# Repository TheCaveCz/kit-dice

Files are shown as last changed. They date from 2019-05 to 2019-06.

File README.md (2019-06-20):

# Throwing Dice / Hrací Kostka

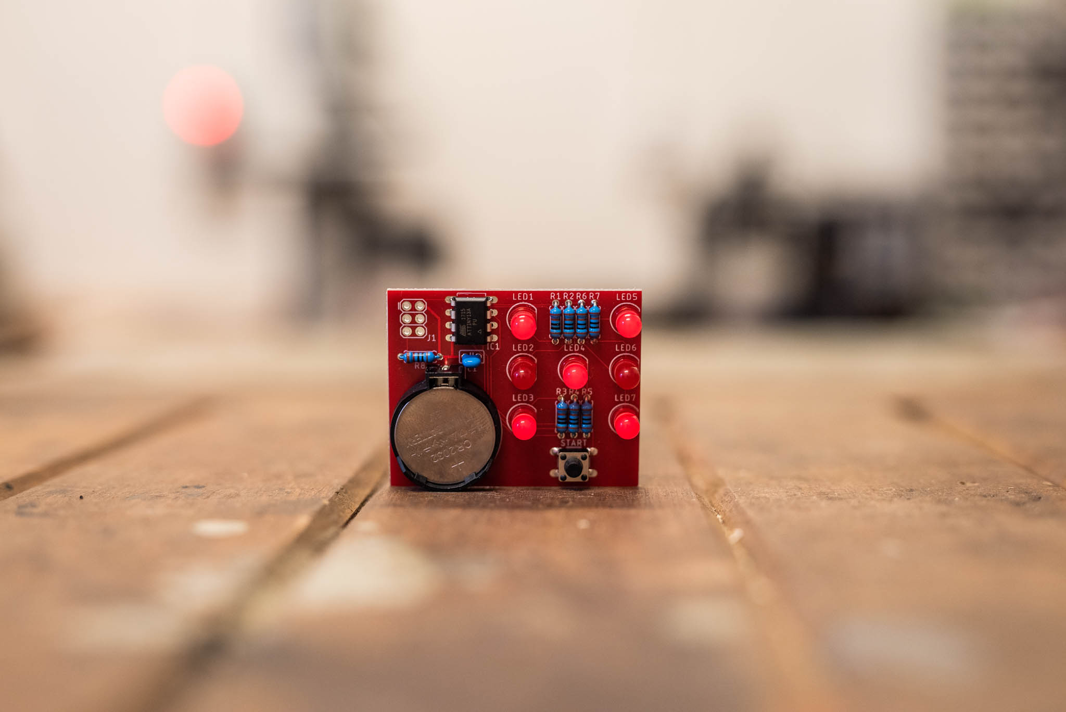
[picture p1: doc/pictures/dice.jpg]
Dice


## Česky

Stavebnice elektronické hrací kostky. Zmáčkni tlačítko start a nech pracovat náhodu.

* [Návod na stavbu](doc/manual-cz.md) ([PDF](doc/manual-cz.pdf))
* [Nahrání nového firmware](doc/firmware-cz.md)

## English

Coming coon...

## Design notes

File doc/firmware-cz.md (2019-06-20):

# Nahrání firmware

Procesory ve stavebnicích už mají program nahraný.

Kód je určený pro Arduino IDE. Pro nahrání do procesoru je nejprve potřeba nainstalovat MicroCore jádro pro ATtiny13 ([https://github.com/MCUdude/MicroCore](https://github.com/MCUdude/MicroCore) ). Žádné další knihovny nejsou potřeba.

Po nainstalování vyber v menu Tools (Nástroje) následující možnosti:

| Možnost | Hodnota |
| --- | --- |
| Board | ATTiny13 |
| BOD | 1.8V |
| LTO | Enabled |
| Clock | 1.2MHz internal OSC |

Procesor ATtiny13 nemá bootloader, takže je potřeba použít programátor (např. AVRisp nebo USBasp). Po připojení programátoru k ISP konektoru J1 v Arduino IDE zvolte možnost "Tools / Burn bootloader" a poté "Sketch / Upload"

---

Příkazová řádka pro avrdude a programátor USBasp:

```
avrdude -pattiny13 -cusbasp -B10 -Pusb -e -Ulock:w:0x3f:m -Uhfuse:w:0xfd:m -Ulfuse:w:0x2A:m -Uflash:w:dice.ino_attiny13a_1200000L.hex:i -Ueeprom:w:`hexdump -n 2 -e '2/1 "0x%02x,"' /dev/random`:m -Ulock:w:0x3e:m
```

bez nastavení generátoru náhodných čísel:

```
avrdude -pattiny13 -cusbasp -B10 -Pusb -e -Ulock:w:0x3f:m -Uhfuse:w:0xfd:m -Ulfuse:w:0x2A:m -Uflash:w:dice.ino_attiny13a_1200000L.hex:i -Ulock:w:0x3e:m
```

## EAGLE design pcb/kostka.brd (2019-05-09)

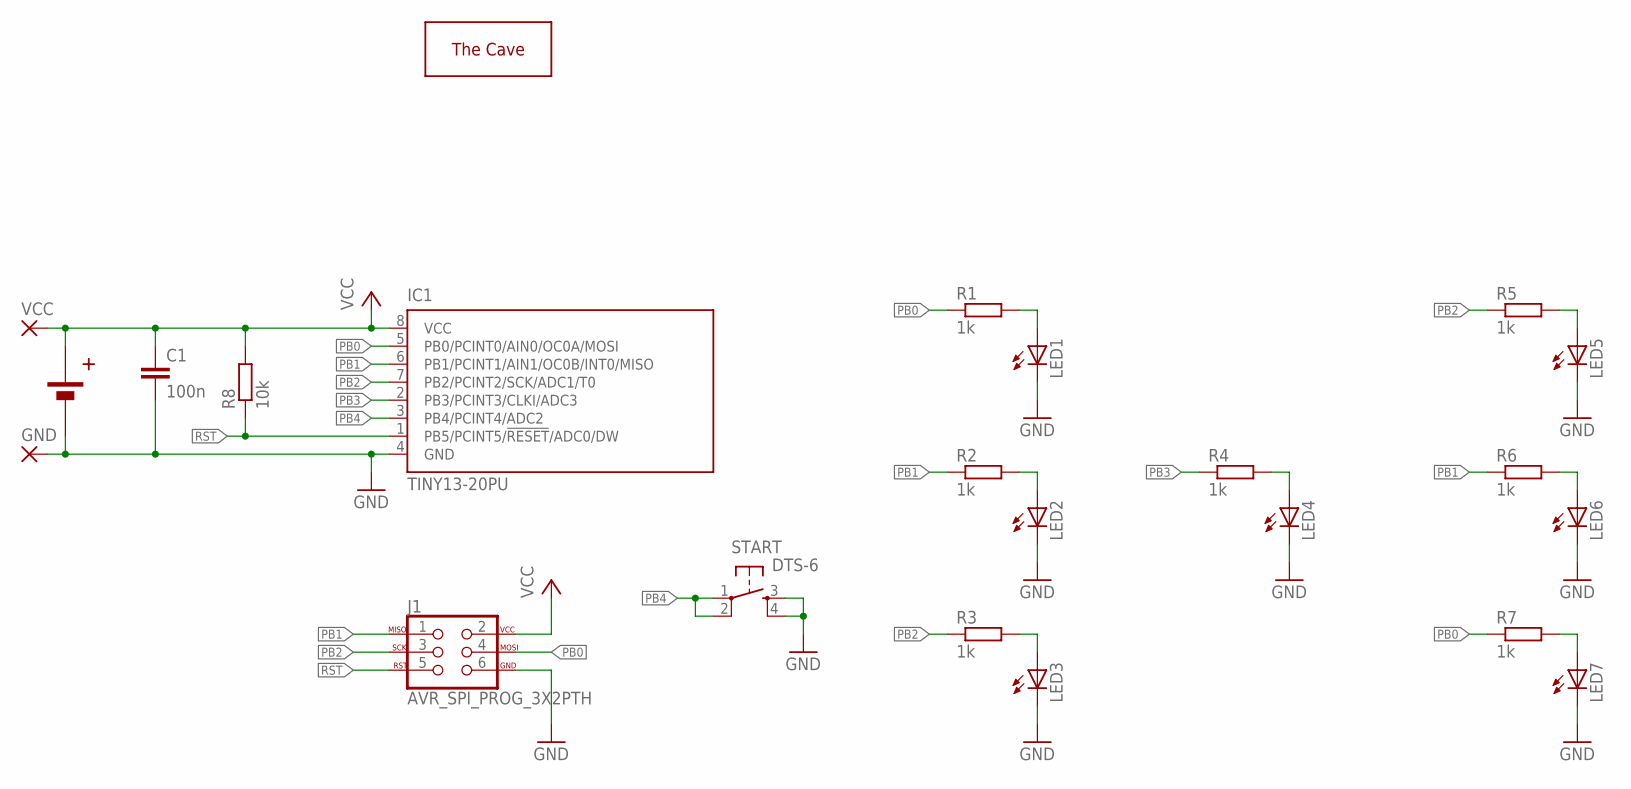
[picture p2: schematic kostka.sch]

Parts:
C1: 100n; C025-025X050
GND: WIREPADSMD1,27-254; SMD1,27-2,54
IC1: TINY13-20PU; DIL08
J1: AVR_SPI_PROG_3X2PTH; 2X3
LED1, LED2, LED3, LED4, LED5, LED6, LED7: LED5MM
R1, R2, R3, R4, R5, R6, R7: 1k; 0207/7
R8: 10k; 0207/7
START: DTS-6
U$1: THECAVE_LOGO_NEW_BOTTOM; NEW_LOGO_BOTTOM
VCC: WIREPADSMD1,27-254; SMD1,27-2,54
X1: CR2032H_HOLD2; CR2032HZ

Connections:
GND: C1.2, GND.1, IC1.4 (GND), J1.6, LED1.K (C), LED2.K (C), LED3.K (C), LED4.K (C), LED5.K (C), LED6.K (C), LED7.K (C), START.3, START.4, X1.MINUS (GND)
unnamed: LED5.A, R5.2
unnamed: LED6.A, R6.2
unnamed: LED7.A, R7.2
unnamed: LED4.A, R4.2
unnamed: LED3.A, R3.2
unnamed: LED2.A, R2.2
unnamed: LED1.A, R1.2
PB0: IC1.5 (PB0/PCINT0/AIN0/OC0A/MOSI), J1.4, R1.1, R7.1
PB1: IC1.6 (PB1/PCINT1/AIN1/OC0B/INT0/MISO), J1.1, R2.1, R6.1
PB2: IC1.7 (PB2/PCINT2/SCK/ADC1/T0), J1.3, R3.1, R5.1
PB3: IC1.2 (PB3/PCINT3/CLKI/ADC3), R4.1
PB4: IC1.3 (PB4/PCINT4/ADC2), START.1, START.2
RST: IC1.1 (PB5/PCINT5/!RESET!/ADC0/DW), J1.5, R8.1
VCC: C1.1, IC1.8 (VCC), J1.2, R8.2, VCC.1, X1.PLUS (VCC)

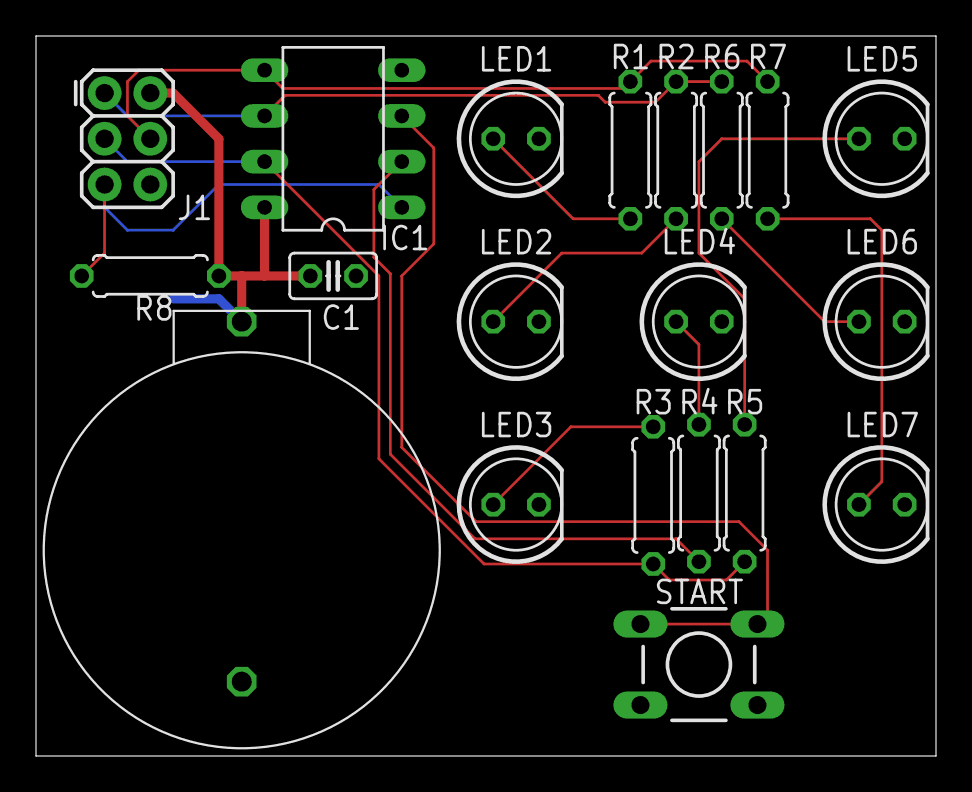
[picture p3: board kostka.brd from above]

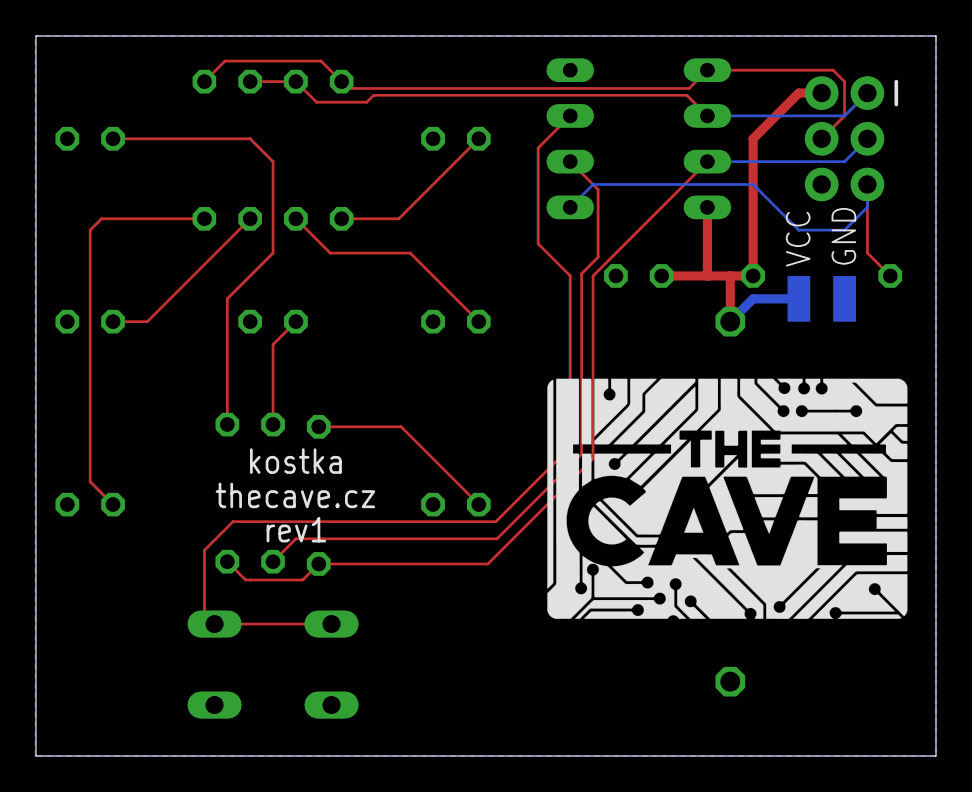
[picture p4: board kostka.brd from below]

Board: 2 copper layers, 50.0 x 40.0 mm, 23 parts (2 on the bottom side), 15 nets.

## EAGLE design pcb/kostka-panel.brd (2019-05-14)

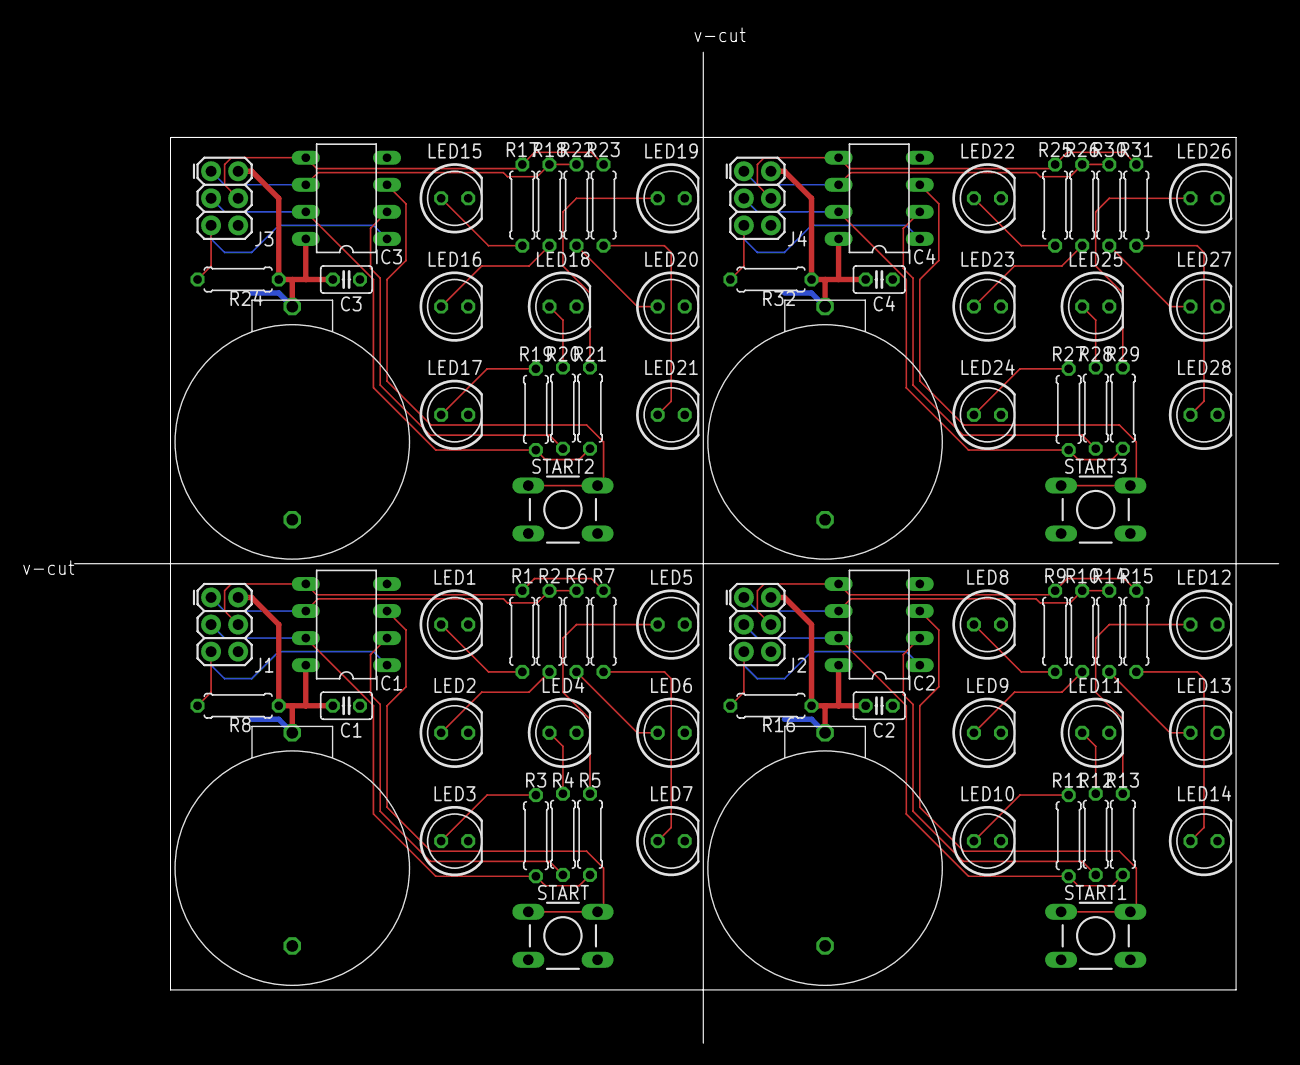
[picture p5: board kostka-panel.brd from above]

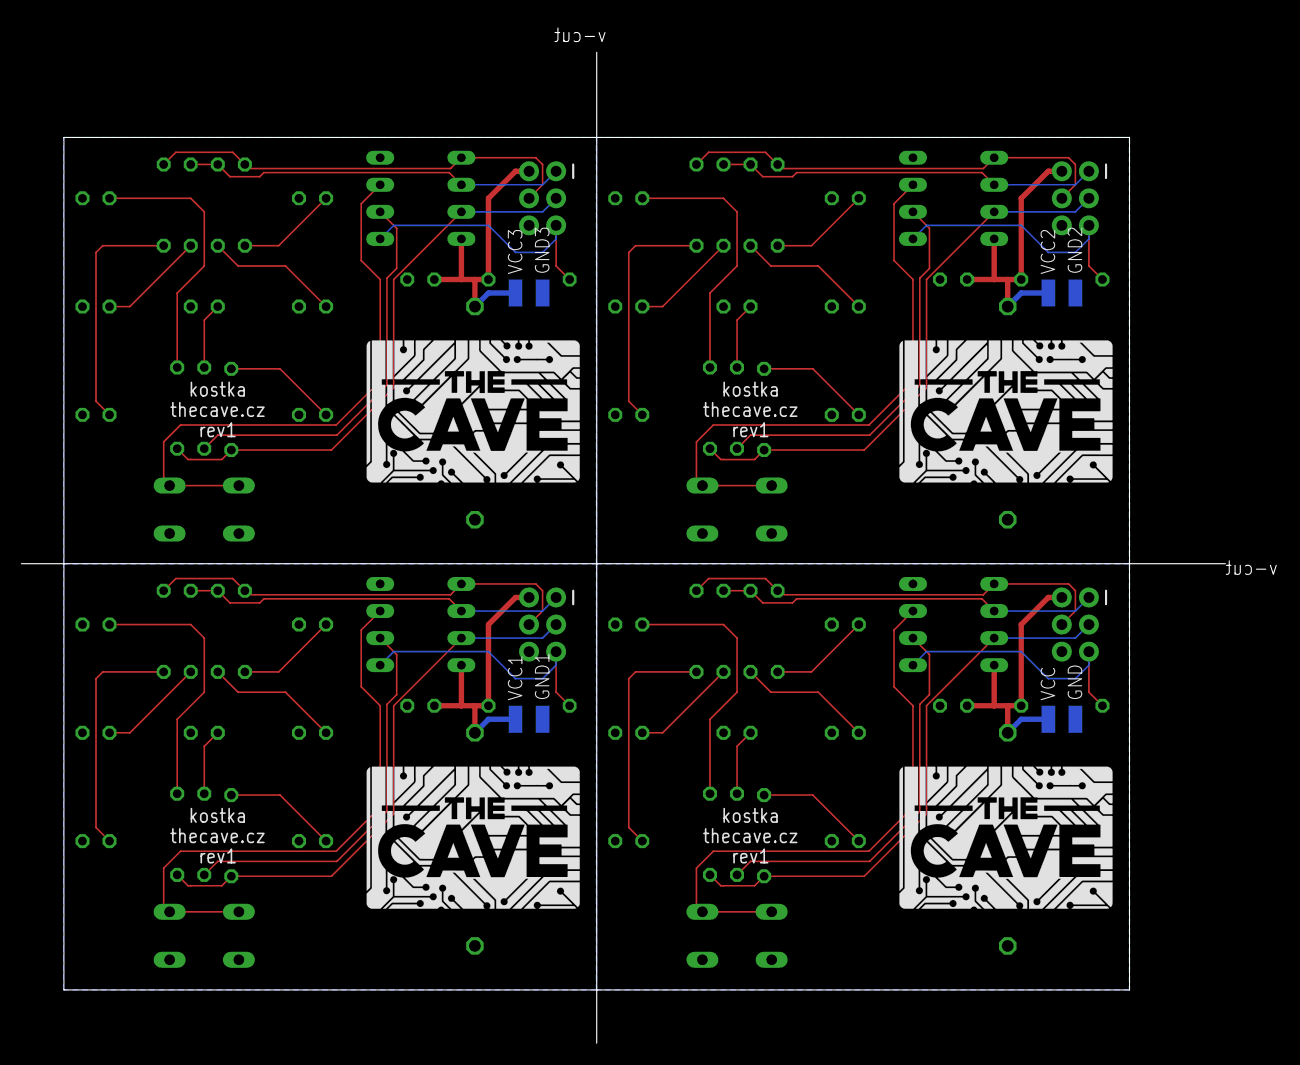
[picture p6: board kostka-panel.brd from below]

Board: 2 copper layers, 100.0 x 80.0 mm, 92 parts (8 on the bottom side), 60 nets.

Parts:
C1, C2, C3, C4: 100n; C025-025X050
GND, GND1, GND2, GND3: SMD1,27-2,54
IC1, IC2, IC3, IC4: TINY13-20PU; DIL08
J1, J2, J3, J4: AVR_SPI_PROG_3X2PTH; 2X3
LED1, LED2, LED3, LED4, LED5, LED6, LED7, LED8, LED9, LED10, LED11, LED12, LED13, LED14, LED15, LED16, LED17, LED18, LED19, LED20, LED21, LED22, LED23, LED24, LED25, LED26, LED27, LED28: LED5MM
R1, R2, R3, R4, R5, R6, R7, R9, R10, R11, R12, R13, R14, R15, R17, R18, R19, R20, R21, R22, R23, R25, R26, R27, R28, R29, R30, R31: 1k; 0207/7
R8, R16, R24, R32: 10k; 0207/7
START, START1, START2, START3: DTS-6
U$1, U$2, U$3, U$4: THECAVE_LOGO_NEW_BOTTOM; NEW_LOGO_BOTTOM
VCC, VCC1, VCC2, VCC3: SMD1,27-2,54
X1, X2, X3, X4: CR2032H_HOLD2; CR2032HZ

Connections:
GND: C1.2, GND.1, IC1.4, J1.6, LED1.K, LED2.K, LED3.K, LED4.K, LED5.K, LED6.K, LED7.K, START.3, START.4, X1.MINUS
GND1: C2.2, GND1.1, IC2.4, J2.6, LED8.K, LED9.K, LED10.K, LED11.K, LED12.K, LED13.K, LED14.K, START1.3, START1.4, X2.MINUS
GND2: C3.2, GND2.1, IC3.4, J3.6, LED15.K, LED16.K, LED17.K, LED18.K, LED19.K, LED20.K, LED21.K, START2.3, START2.4, X3.MINUS
GND3: C4.2, GND3.1, IC4.4, J4.6, LED22.K, LED23.K, LED24.K, LED25.K, LED26.K, LED27.K, LED28.K, START3.3, START3.4, X4.MINUS
unnamed: LED12.A, R13.2
unnamed: LED5.A, R5.2
unnamed: LED13.A, R14.2
unnamed: LED6.A, R6.2
unnamed: LED14.A, R15.2
unnamed: LED7.A, R7.2
unnamed: LED11.A, R12.2
unnamed: LED4.A, R4.2
unnamed: LED10.A, R11.2
unnamed: LED3.A, R3.2
unnamed: LED9.A, R10.2
unnamed: LED2.A, R2.2
unnamed: LED8.A, R9.2
unnamed: LED1.A, R1.2
unnamed: LED19.A, R21.2
unnamed: LED20.A, R22.2
unnamed: LED21.A, R23.2
unnamed: LED18.A, R20.2
unnamed: LED17.A, R19.2
unnamed: LED16.A, R18.2
unnamed: LED15.A, R17.2
unnamed: LED26.A, R29.2
unnamed: LED27.A, R30.2
unnamed: LED28.A, R31.2
unnamed: LED25.A, R28.2
unnamed: LED24.A, R27.2
unnamed: LED23.A, R26.2
unnamed: LED22.A, R25.2
PB0: IC1.5, J1.4, R1.1, R7.1
PB1: IC1.6, J1.1, R2.1, R6.1
PB2: IC1.7, J1.3, R3.1, R5.1
PB3: IC1.2, R4.1
PB4: IC1.3, START.1, START.2
PB5: IC2.5, J2.4, R9.1, R15.1
PB6: IC2.6, J2.1, R10.1, R14.1
PB7: IC2.7, J2.3, R11.1, R13.1
PB8: IC2.2, R12.1
PB9: IC2.3, START1.1, START1.2
PB10: IC3.5, J3.4, R17.1, R23.1
PB11: IC3.6, J3.1, R18.1, R22.1
PB12: IC3.7, J3.3, R19.1, R21.1
PB13: IC3.2, R20.1
PB14: IC3.3, START2.1, START2.2
PB15: IC4.5, J4.4, R25.1, R31.1
PB16: IC4.6, J4.1, R26.1, R30.1
PB17: IC4.7, J4.3, R27.1, R29.1
PB18: IC4.2, R28.1
PB19: IC4.3, START3.1, START3.2
RST: IC1.1, J1.5, R8.1
RST1: IC2.1, J2.5, R16.1
RST2: IC3.1, J3.5, R24.1
RST3: IC4.1, J4.5, R32.1
VCC: C1.1, IC1.8, J1.2, R8.2, VCC.1, X1.PLUS
VCC1: C2.1, IC2.8, J2.2, R16.2, VCC1.1, X2.PLUS
VCC2: C3.1, IC3.8, J3.2, R24.2, VCC2.1, X3.PLUS
VCC3: C4.1, IC4.8, J4.2, R32.2, VCC3.1, X4.PLUS

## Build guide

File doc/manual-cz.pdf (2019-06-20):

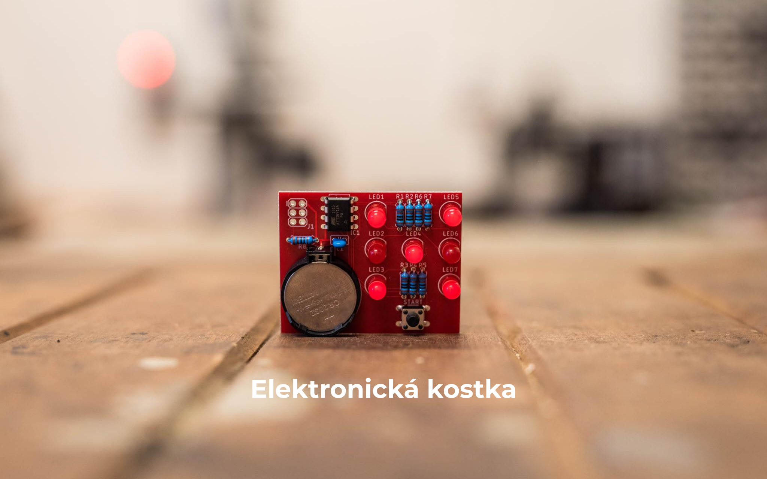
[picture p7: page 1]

## Elektronická kostka

## Součástky

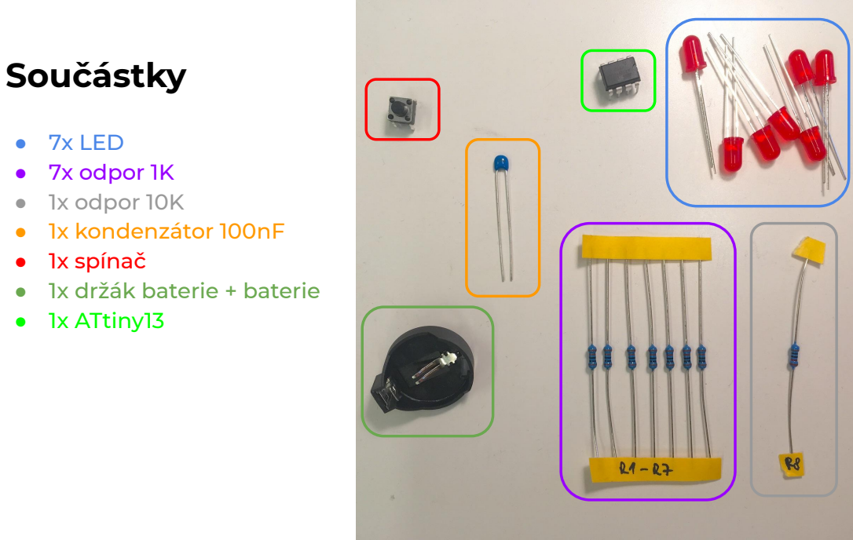
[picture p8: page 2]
● 7x LED ● 7x odpor 1K ● 1x odpor 10K ● 1x kondenzátor 100nF ● 1x spínač ● 1x držák baterie + baterie ● 1x ATtiny13

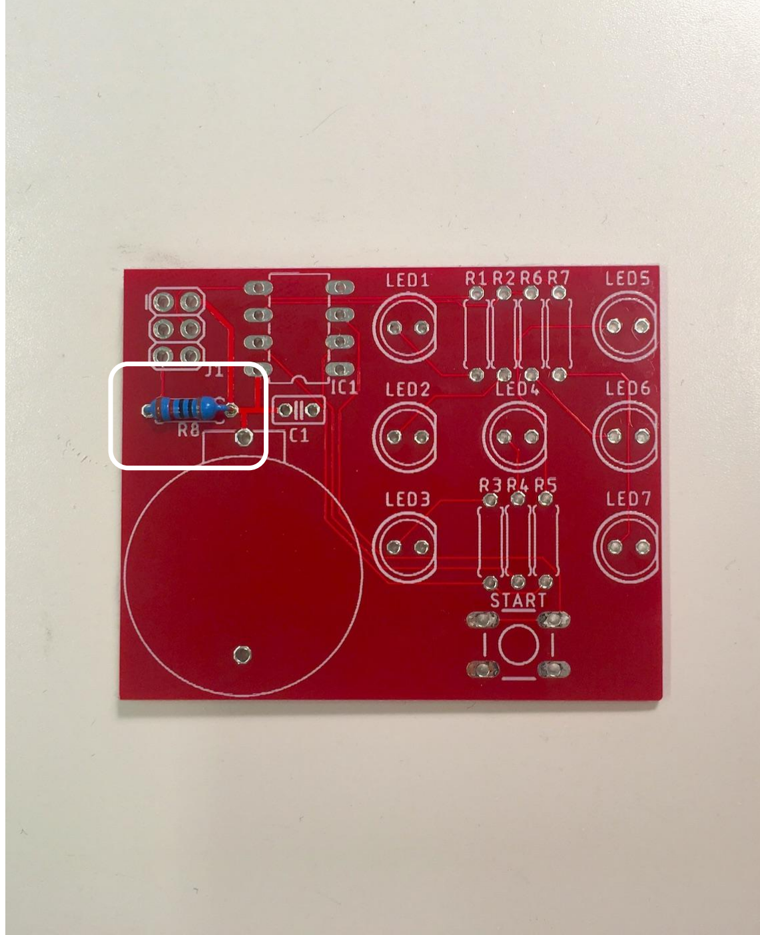
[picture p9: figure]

## Krok 1

- Odpor R8 (10K) - 1ks
- Ohnout vývody těsně u těla odporu
- Vložit na místo označené R8
- Nezáleží na orientaci
- Připájet

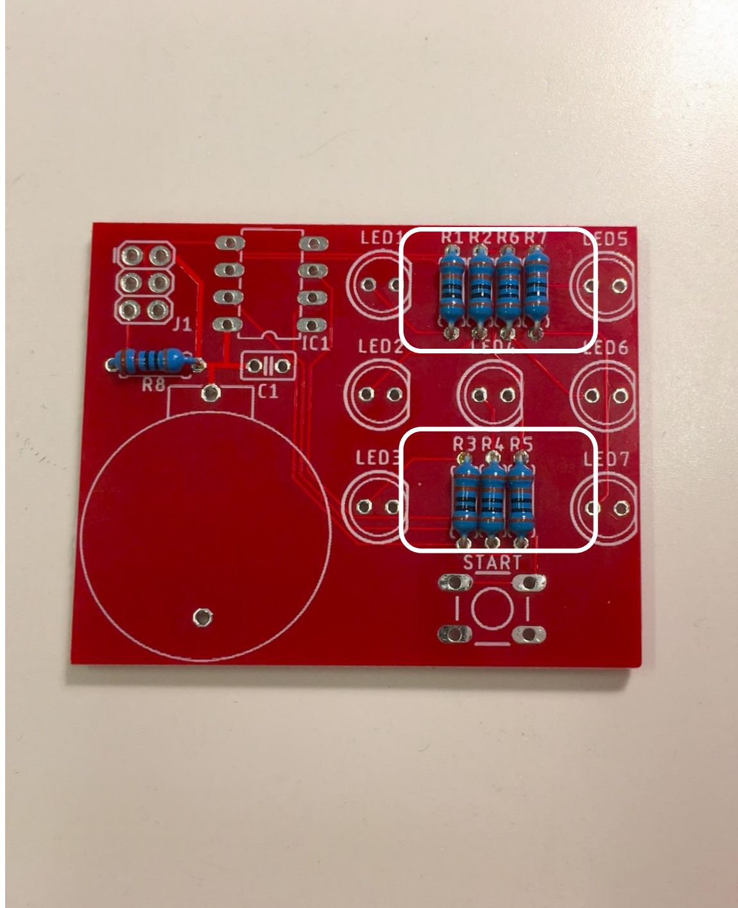
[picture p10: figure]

## Krok 2

- Odpory R1-R7 (1K) - 7ks
- Ohnout vývody těsně u těla odporu
- Vložit na místa označená R1 až R7
- Nezáleží na orientaci
- Připájet

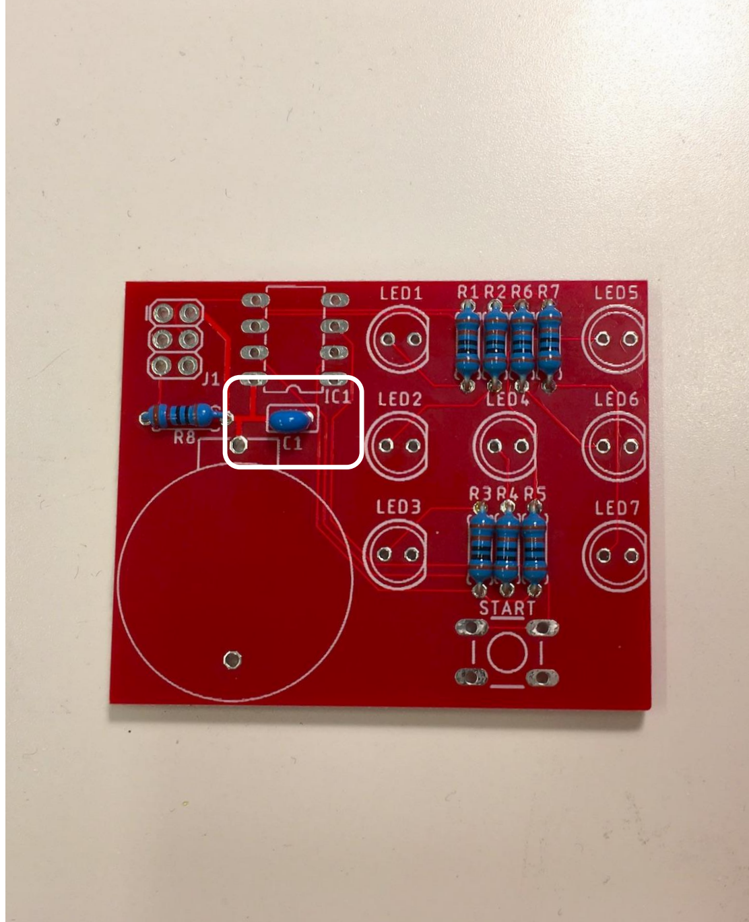
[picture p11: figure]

## Krok 3

- Kondenzátor C1 (100nF) - 1ks
- Vložit na místo označené C1
- Nezáleží na orientaci
- Připájet

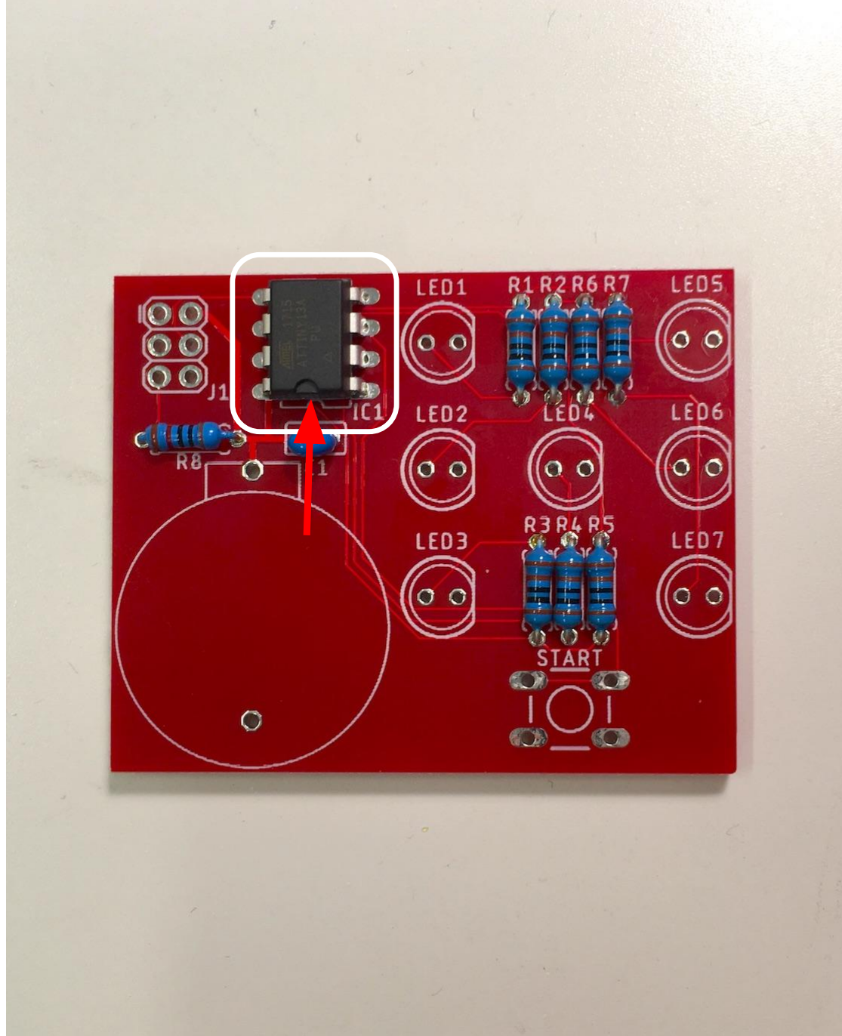
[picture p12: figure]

## Krok 4

- Čip ATtiny13 - 1ks
- Vložit na místo označené IC1
- Pozor na orientaci, na čipu je značka
- Připájet

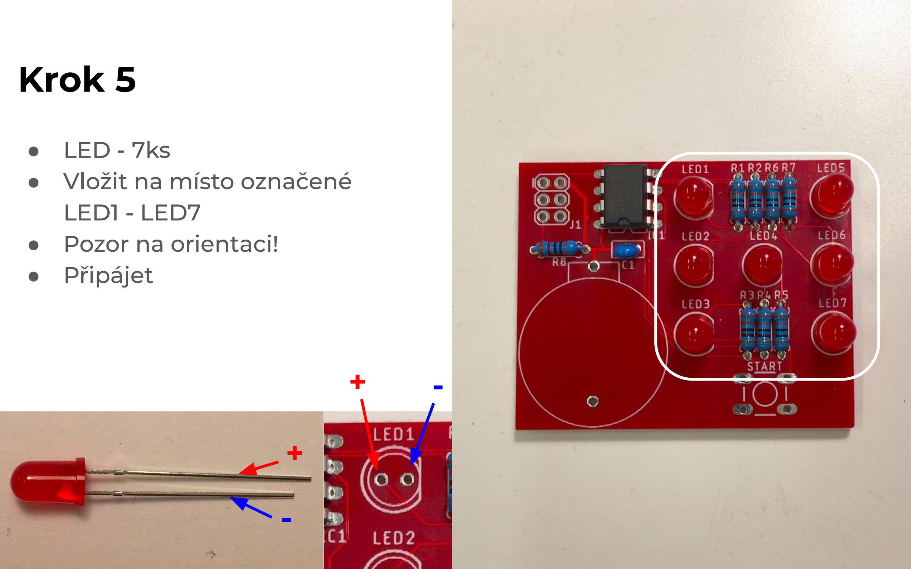
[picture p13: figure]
Krok 5; ● LED - 7ks ● Vložit na místo označené LED1 - LED7 ● Pozor na orientaci! ● Připájet

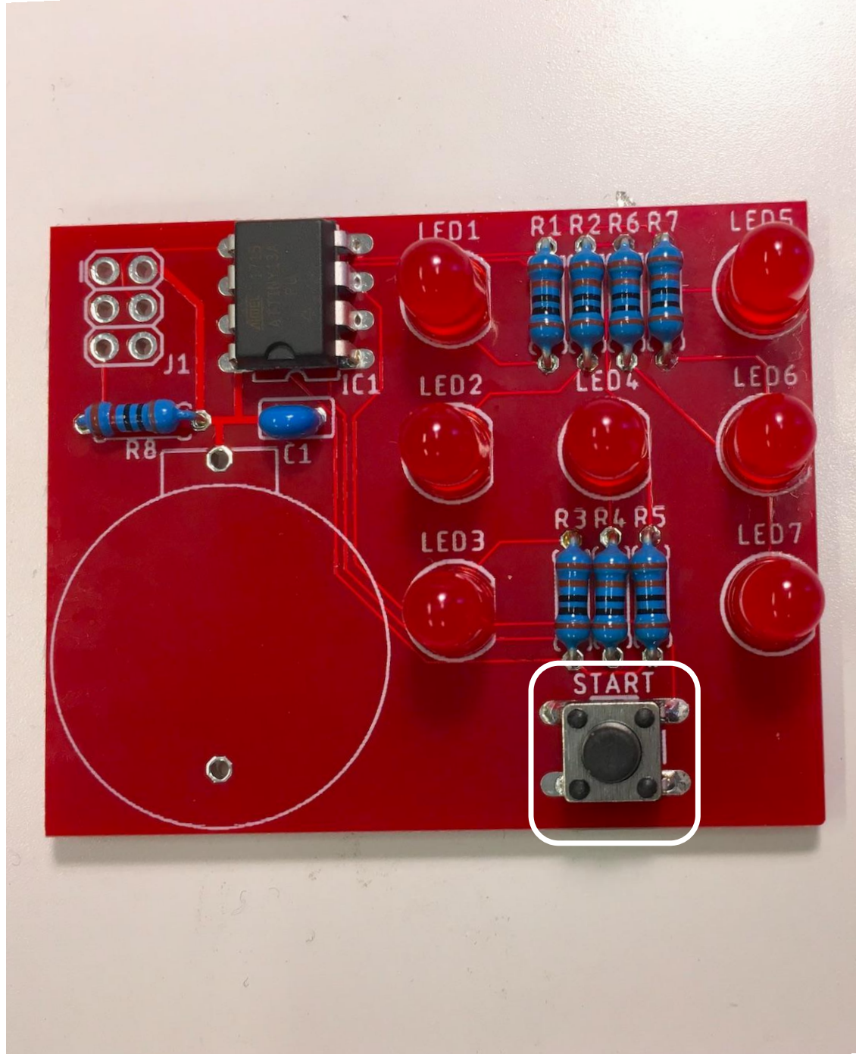
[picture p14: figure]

## Krok 6

- Spínač - 1ks
- Vložit na místo označené START
- Nezáleží na orientaci
- Připájet

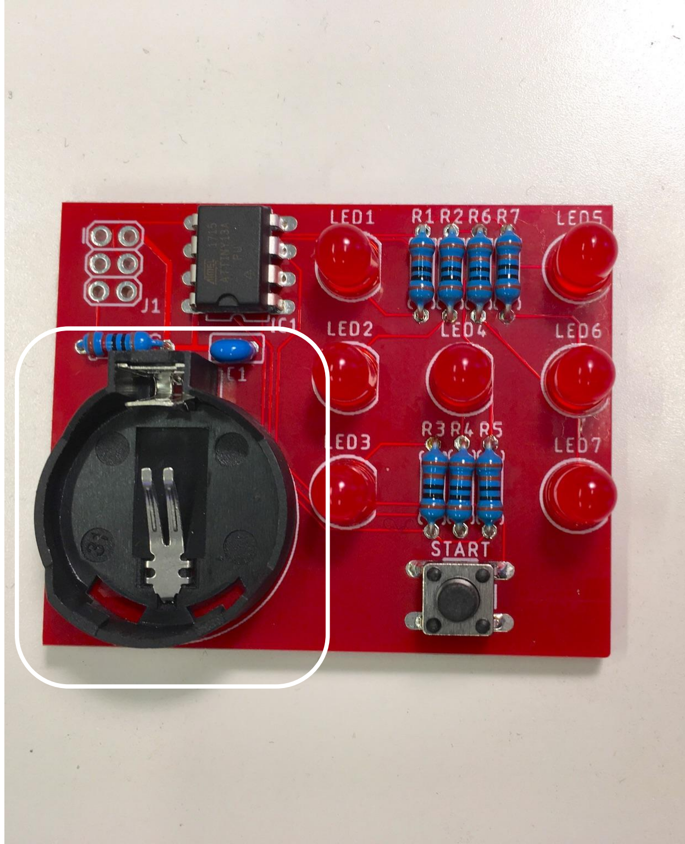
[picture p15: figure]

## Krok 7

- Držák baterie - 1ks
- Připájet

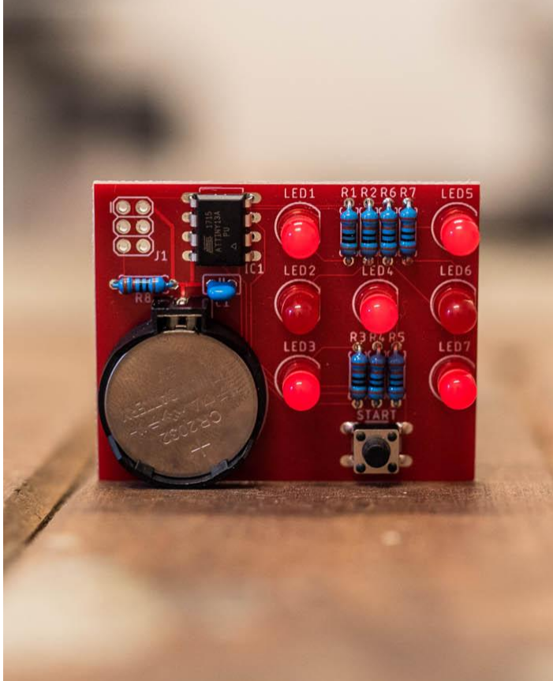
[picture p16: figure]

## Hotovo!

- Vložit baterii plusem nahoru
- Stisknout tlačítko START

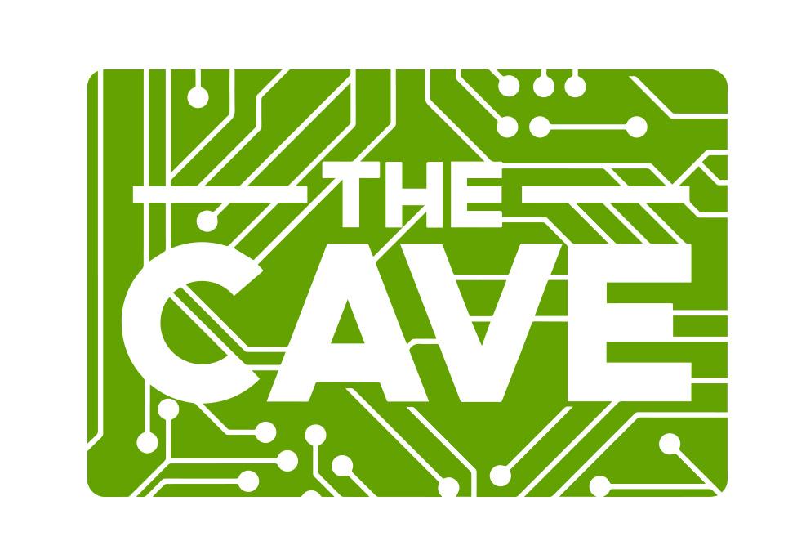
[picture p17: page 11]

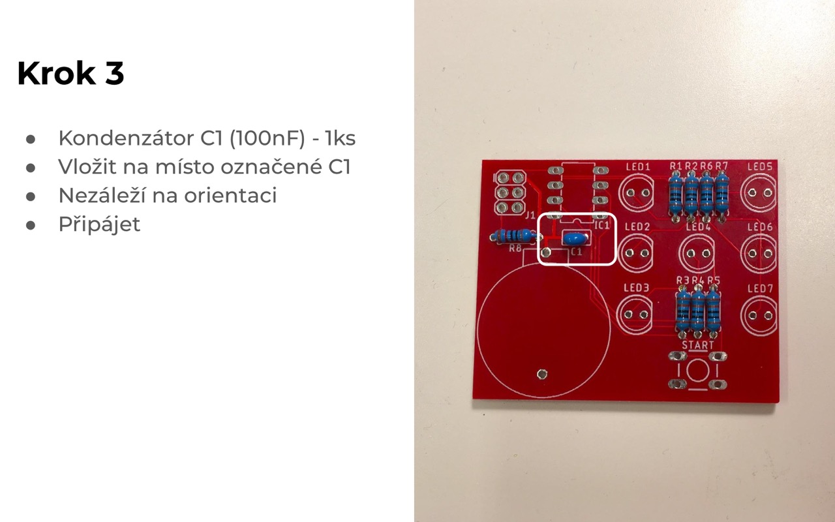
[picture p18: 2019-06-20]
doc/pictures/manual-cz-5.jpeg

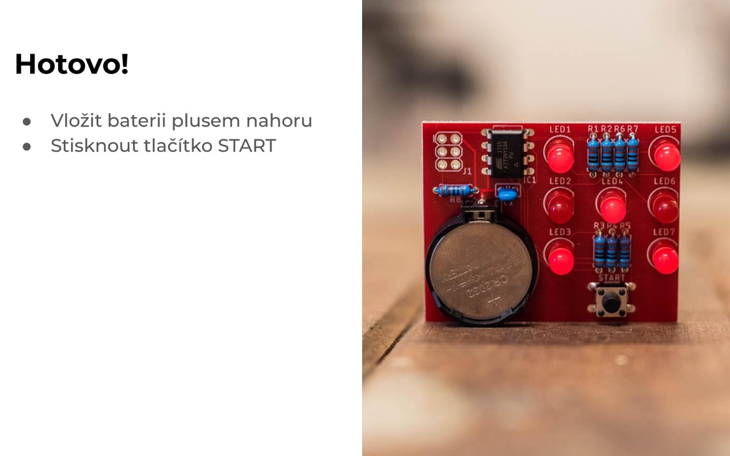
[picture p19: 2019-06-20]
doc/pictures/manual-cz-10.jpeg

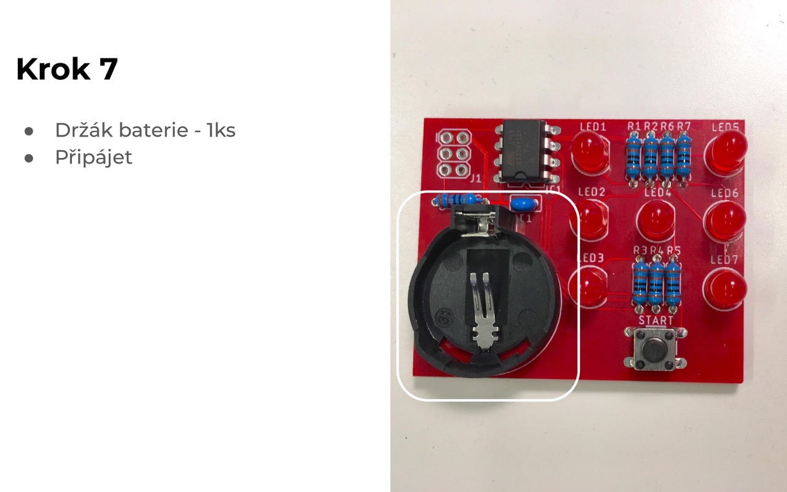
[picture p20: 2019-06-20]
doc/pictures/manual-cz-9.jpeg

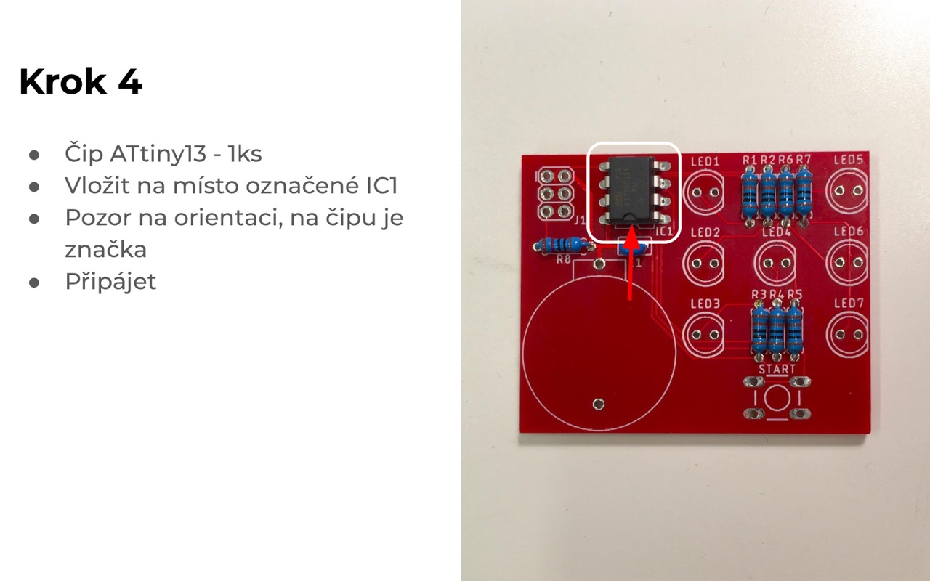
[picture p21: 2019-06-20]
doc/pictures/manual-cz-6.jpeg

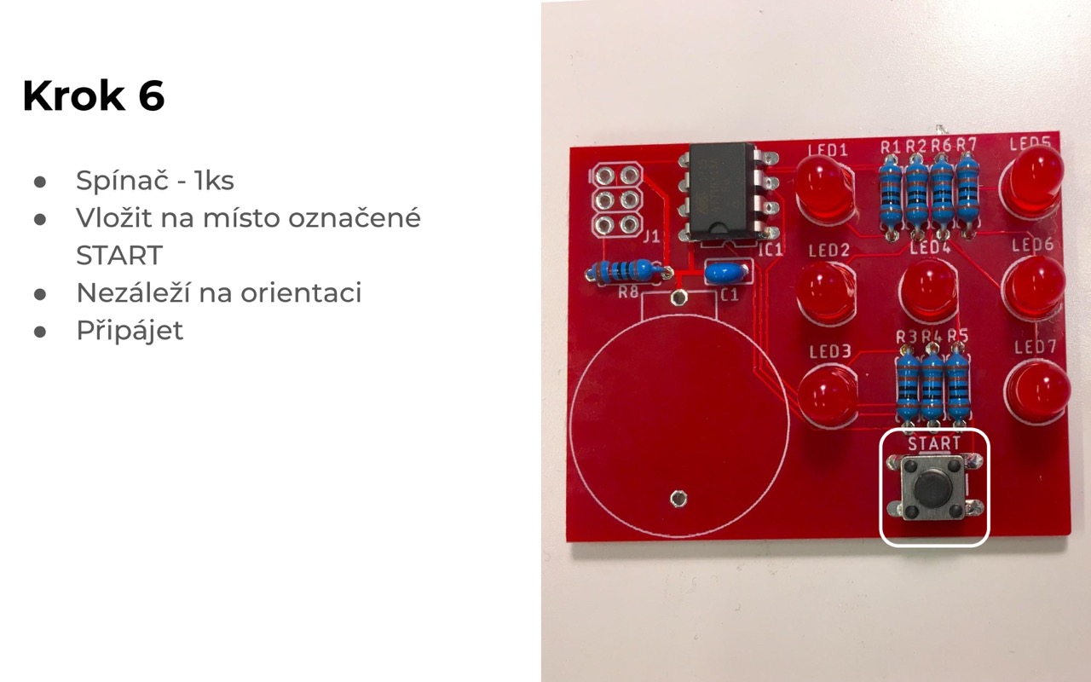
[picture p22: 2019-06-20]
doc/pictures/manual-cz-8.jpeg

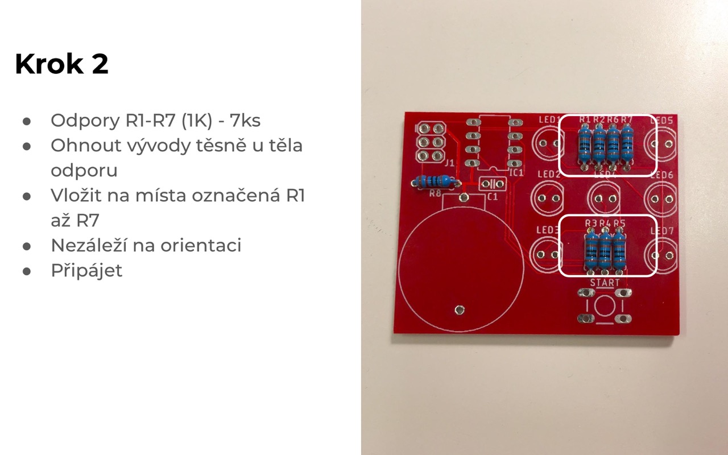
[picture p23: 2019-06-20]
doc/pictures/manual-cz-4.jpeg

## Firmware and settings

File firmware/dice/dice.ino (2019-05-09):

/*
   Dice kit firmware

   The Cave, 2019
   https://thecave.cz

   Licensed under MIT License (see LICENSE file for details)

   using MicroCore (https://github.com/MCUdude/MicroCore)

   Board: ATTiny13
   BOD: 1.8V
   LTO: Enabled
   Clock: 1.2MHz internal OSC

*/
#include <avr/pgmspace.h>
#include <avr/interrupt.h>
#include <avr/sleep.h>
#include <avr/wdt.h>
#include <avr/eeprom.h>


#define PIN_BTN 4
#define NUMBER_EMPTY 6

const uint8_t numbers[7] PROGMEM = {
  0b1000,
  0b0100,
  0b1100,
  0b0101,
  0b1101,
  0b0111,
  0b0000,
};


void setup() {
  // turn off adc/wdt to save power
  WDTCR = 0;
  ADCSRA = 0;

  // wake up when PIN_BTN state changes
  sleepSetup(_BV(PIN_BTN));

  randomSetup();
}

uint8_t buttonRead() {
  return !(PINB & _BV(PIN_BTN));
}

void showNumber(const uint8_t n) {
  PORTB = pgm_read_byte(numbers + n) | _BV(PIN_BTN);
}

void goToSleep() {
  // all pins as inputs
  DDRB = 0;
  PORTB = _BV(PIN_BTN);
  // enter sleep
  sleepEnter();
  // set led pins as outputs, set button as input_pullup
  DDRB = 0b01111;
}

void loop() {
  goToSleep();
  if (!buttonRead()) return;

  uint8_t d = 50;
  uint8_t cnt = 20;
  uint8_t n = 0, n1 = 0;
  while (cnt--) {
    while (n == n1) {
      n1 = randomN(6);
    }
    n = n1;
    showNumber(n);
    delay(d);
    d += 5;
  }

  delay(1000);

  cnt = 3;
  while (cnt--) {
    showNumber(NUMBER_EMPTY);
    delay(250);
    showNumber(n);
    delay(250);
  }
}

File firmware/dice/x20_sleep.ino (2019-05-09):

ISR (PCINT0_vect) {
  // disable interrupt enable flag
  GIMSK &= ~(_BV(PCIE));
}

void sleepEnter() {
  cli();

  wdt_reset();

  // enable iterrupt on change and clear interrupt flag
  GIFR = _BV(PCIF);
  GIMSK |= _BV(PCIE);

  // enable possibility to enter sleep mode
  sleep_enable();
  // disable BOD - needs to be done exactly before sleep
  sleep_bod_disable();
  // enable interrupts (on change interrupt) to wake the cpu
  sei();
  // go to sleep finally
  sleep_cpu();
  // disable possibility to enter sleep mode
  sleep_disable();
  // enable interrupts (just for sure)
  sei();
}

void sleepSetup(const uint8_t pcmsk) {
  // select sleep mode and configure on-change interrupt source
  set_sleep_mode(SLEEP_MODE_PWR_DOWN);
  PCMSK = pcmsk;
}

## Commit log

2019-05-09 Add firmware and pcb
    [kostka.brd, kostka.sch]
2019-05-14 Add gerber files
    [kostka-panel.brd]

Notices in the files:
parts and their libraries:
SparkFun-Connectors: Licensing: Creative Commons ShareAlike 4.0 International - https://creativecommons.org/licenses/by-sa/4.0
